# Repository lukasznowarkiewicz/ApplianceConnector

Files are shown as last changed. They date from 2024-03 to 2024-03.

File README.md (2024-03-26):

# Appliance connector

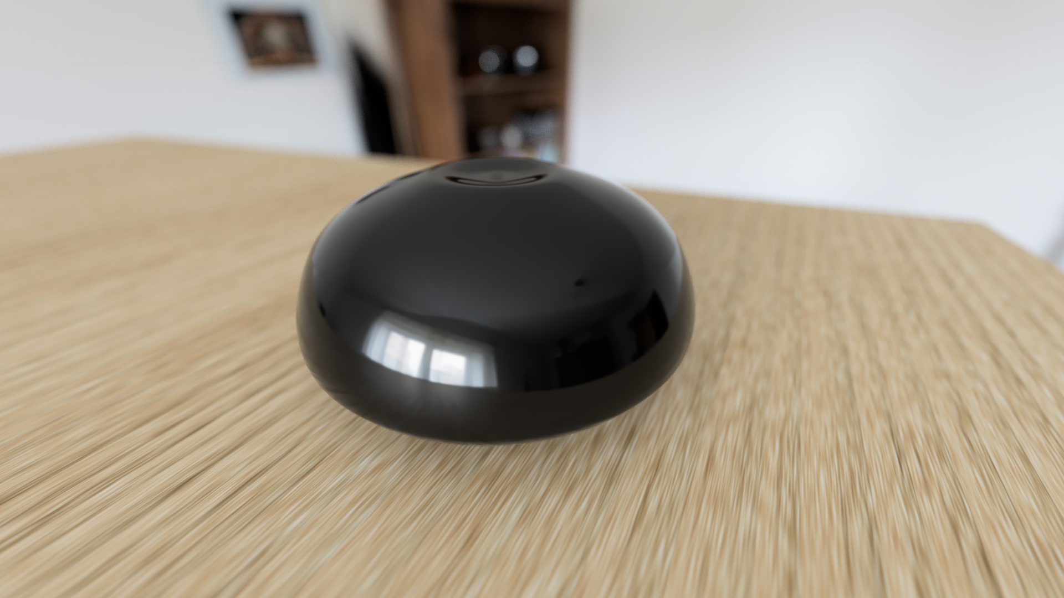
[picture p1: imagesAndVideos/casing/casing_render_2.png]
Applicance connector render


## Initial idea - visible gap on the market

The history behing this device came from my experience - I used to install smart home systems and saw some market gap in integrating smart home devices which oryginally was not intended to be "smart". I have in mind devices controlled over infrared, like air condationers, TVs, home theaters, audio systems, satellite and cable boxes, projectors, controlled over serial port (RS-232), like projectors, some audio entertainment systems, video conferencing systems, surveillance camera systems, etc., finishing on most simple, controlled with dry contact, like garage and gate openers, access control systems or blinds and curtains systesm, to just name a few. Backbone of most smart home systems in the end, almost always is TCP/IP network. Proabably the most universal method between both vendor locked and open smart home systems is communication via REST API. This device main prupose was to cover this gap, allow integration of all listed devices in thoughtfully manner. 

## Similar devices

Back in 2019, when we were working on this device, already some alternatives existed. There were deivces, which adresses only part of the problem. To list a few:

### Global Cache iTach

- **Pros**: Supports various connection options, compact, compatible with many systems.
- **Cons**: Setup complexity, may not suit simple needs, separate devices for RS232 and IR, high price

### BroadLink RM Pro+

- **Pros**: Affordable, supports IR and RF 433MHz, works with major voice assistants.
- **Cons**: RF control issues reported, app usability, lack of REST API.

### Remotec AC Master ZXT-600

- **Pros**: Specialized for AC control, supports major brands, energy-efficient.
- **Cons**: Limited to AC, setup complexity with certain hubs, lack of REST API.

### Blastbot IR Blaster

- **Pros**: Smartphone and voice control, supports schedules.
- **Cons**: Cloud dependency, IR only, lack of REST API.

### Remotec ZXT-310US

- **Pros**: Z-Wave to IR for AV devices, supports learning IR codes.
- **Cons**: Focus on AV, manual configuration for uncommon devices, lack of REST API.

### Hank IR Transceiver

- **Pros**: Z-Wave Plus, IR learning, compact.
- **Cons**: AV control focus, setup technicality, lack of REST API.

### Xiaomi Universal IR Remote Controller

- **Pros**: Very affordable, wide device support, integrates with Mi Home.
- **Cons**: Wi-Fi dependency, app/setup challenges for non-Chinese speakers, lack of REST API.

### Logitech Harmony

- **Pros**: Broad device compatibility, advanced automation, supports multiple connection types.
- **Cons**: Higher cost, discontinued models may affect support, lack of REST API.

## First prototype

First prototype was rough. Designed in `Autodesk Eagle` (shortly after buying it from CadSoft). It only purpose was to get rid off breadboards, which often cause more problems than circuit itself. This devkit was an extension to `Lolin32 Lite` prototyping board. This board I would call as "it ain't much, but it honest work" and most important allowed us quick start working on the software.

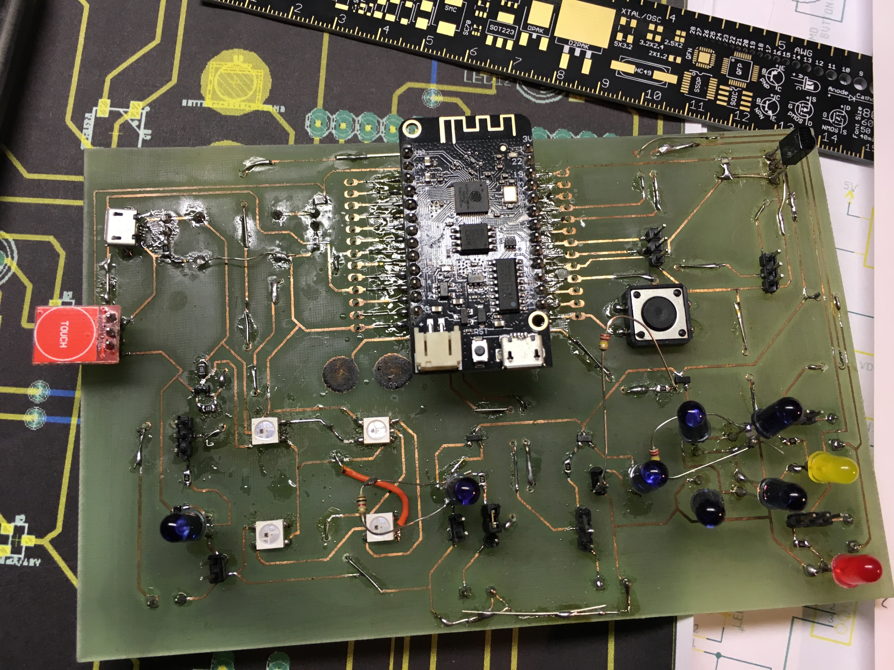
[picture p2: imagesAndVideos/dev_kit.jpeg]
DevKit photo


It has necessary components for testing initially agreed functionalities:
- IR leds for controlling devices
- IR receiver `PNA460XM`
- two experimental touch buttons (ESP32 has itself option for capacitive buttons support, but in the end we were unable to figure out how to make it work)
- connector for `TTTP223` based touch button module
- `WS2812B` Leds for showing status of the device
  
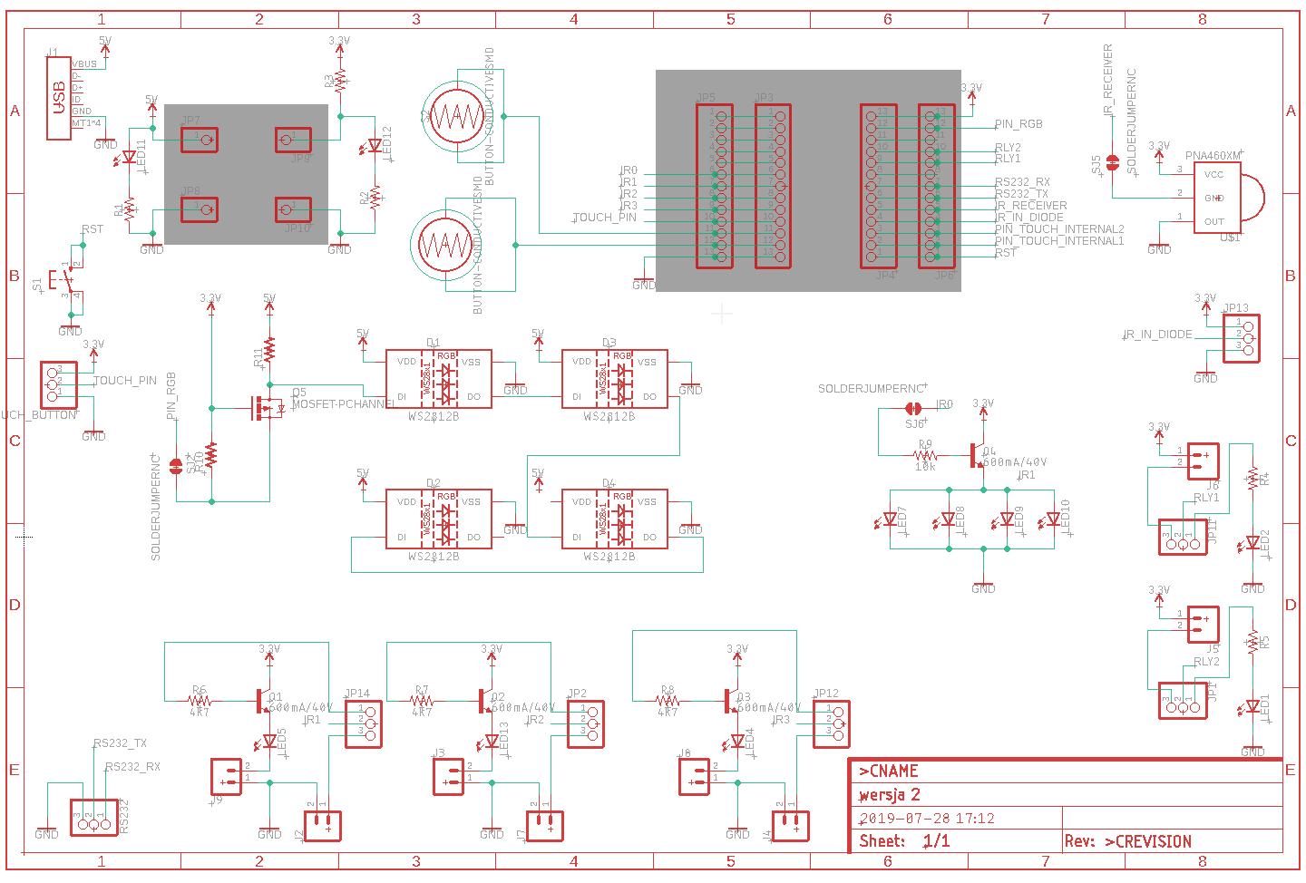
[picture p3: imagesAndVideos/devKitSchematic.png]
DevKit schematic


## Functional requirements and UI design

At this point we more or less know how device should function, which features implement. Form of the device was not clear yet, but anyway it didn't stop us from working on software. Basic user interface was designed in `Affinity Designer`. Simple mockup of the software, not functional, but give us good base for creating user interface in web technologies.

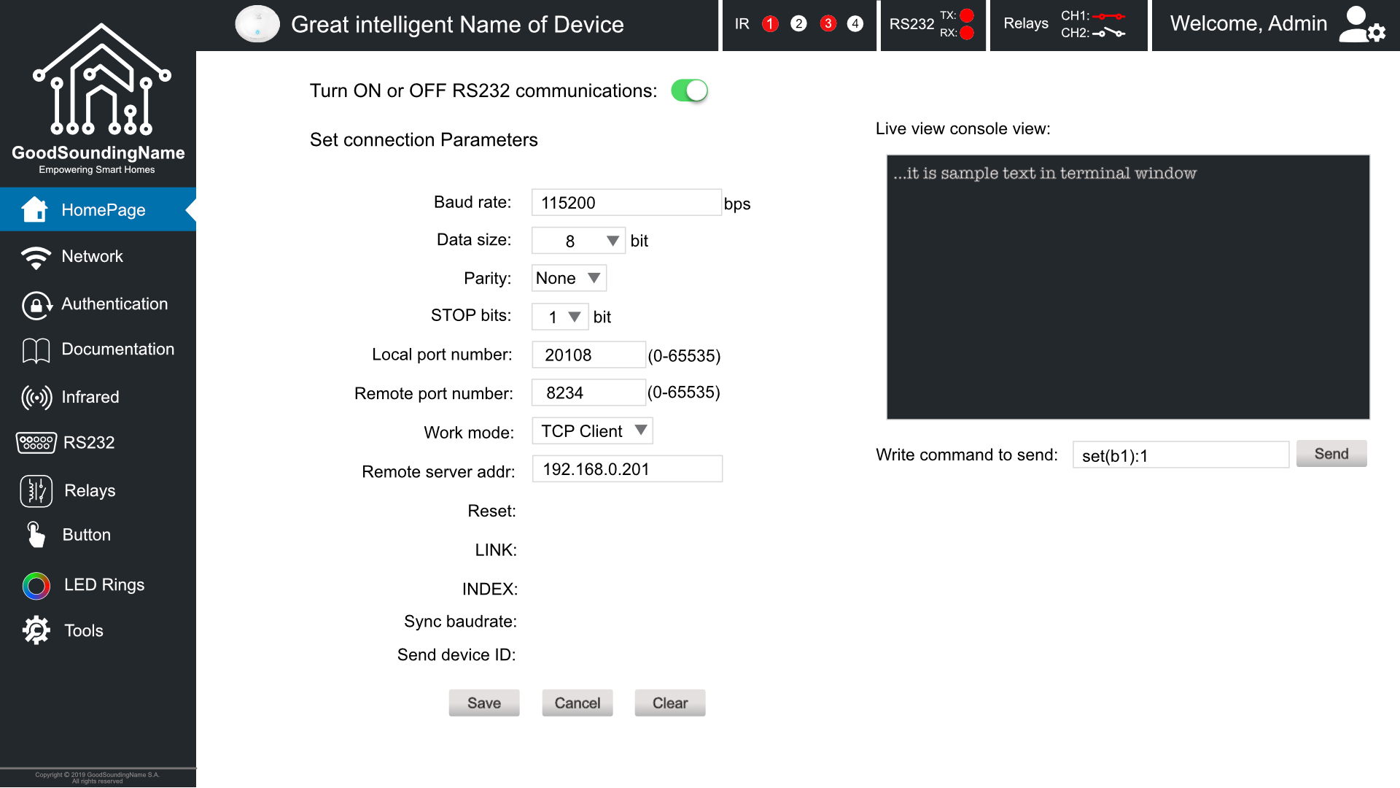
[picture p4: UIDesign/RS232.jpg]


## Software Development

The web server runs directly on the ESP32, necessitating that the webpage be as simple and lightweight as possible. With only 4MB of storage available, every kilobyte counted. Most images used were .svg, and wherever feasible, they were generated using CSS to save space.

The ESP32 operates on `ESP-IDF FreeRTOS`. Developing such an advanced application in plain C—especially incorporating functions like Wi-Fi connection, filesystem management, and web server functionalities—would significantly increase the app's complexity.

### Frontend

Given the storage limitations, the frontend was designed to be straightforward and lightweight. This is why we opted not to use any frameworks for creating the GUI. It was crafted using simple HTML, with CSS for styling and JavaScript for websockets to minimize overhead and ensure efficiency.

https://github.com/lukasznowarkiewicz/ApplianceConnector/assets/82212257/3271daf3-c359-4126-b65f-c0a6bbfbe71e

### Backend

The backend of this application on the ESP32, utilizing ESP-IDF FreeRTOS, comprises various components, each managed by specific files:

- **Webserver**: `webserver.c` and `webserver.h` handle HTTP requests, serving the GUI files and processing API calls from the frontend. `webserver_types.h` likely defines the structures and enums used by the webserver.

- **Wi-Fi Connection**: `netConf.c` and `netConf.h` are responsible for configuring the Wi-Fi connection, handling tasks such as connecting to the Wi-Fi network and managing network settings.

- **Infrared Control**:
  - Sending IR commands: `irsend.c` and `irsend.h` manage the sending of IR commands to devices.
  - Receiving IR commands: `irrecv.c` and `irrecv.h` handle the reception of IR signals from remote controls.

- **UART Communication**: `tcpserial.c` and `tcpserial.h` handle of UART communication.

- **LED Control**: `led.c` and `led.h` are used for controlling LED indicators on the ESP32, such as showing the status of the device or Wi-Fi connection.

- **Relay Control**: `relay.c` and `relay.h` manage the activation and deactivation of relays for controlling dry contacts.

- **Button Input**: `button.c` and `button.h` handle input from physical buttons on the ESP32 device, allowing for user interaction without the web interface.

### Testing infrared

Testing receiving commands from IR:

https://github.com/lukasznowarkiewicz/ApplianceConnector/assets/82212257/00d33be0-9f63-4c23-b90f-50ff3d0fc727

Testing sending commands over IR:

https://github.com/lukasznowarkiewicz/ApplianceConnector/assets/82212257/5f554944-b339-42f7-858e-584611f51841

Saving received commands to text file (as a config):

https://github.com/lukasznowarkiewicz/ApplianceConnector/assets/82212257/204f5668-1959-4dcd-b433-fa26de5b123a

### Testing UART

https://github.com/lukasznowarkiewicz/ApplianceConnector/assets/82212257/dbb3c007-76f6-457e-a3c8-33a27682dad4

### Testing relays

https://github.com/lukasznowarkiewicz/ApplianceConnector/assets/82212257/7d674879-574c-41a6-804a-36f65532bcf2

## Enclosure

After we made first functioning prorotype - it was time to pack this device into sleek housing. Many ideas was both designed and 3d printed. 

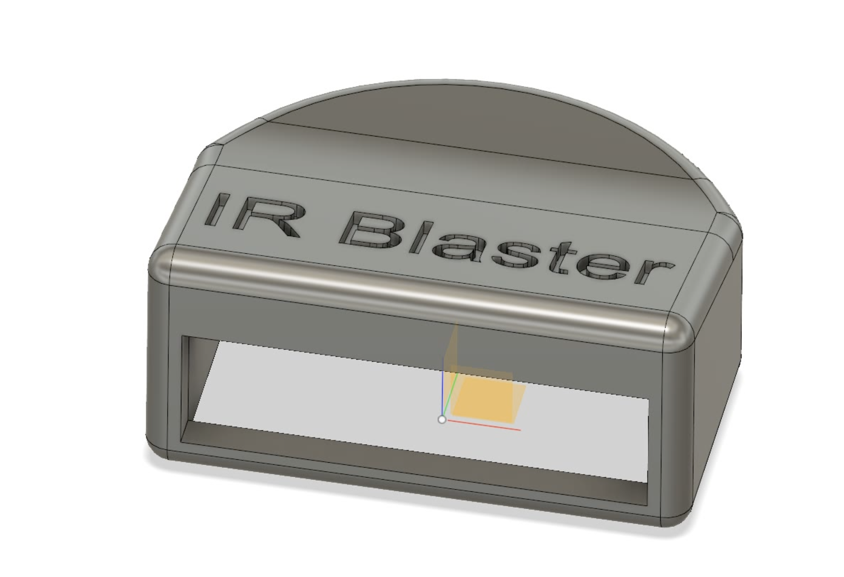
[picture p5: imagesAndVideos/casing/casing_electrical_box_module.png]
Applicance connector casing brainstorming 1


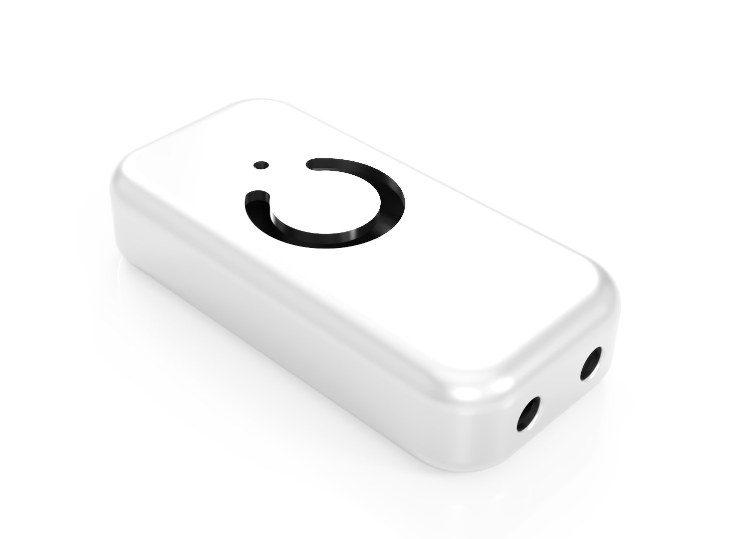
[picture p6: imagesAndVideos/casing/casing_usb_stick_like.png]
Applicance connector casing brainstorming 2


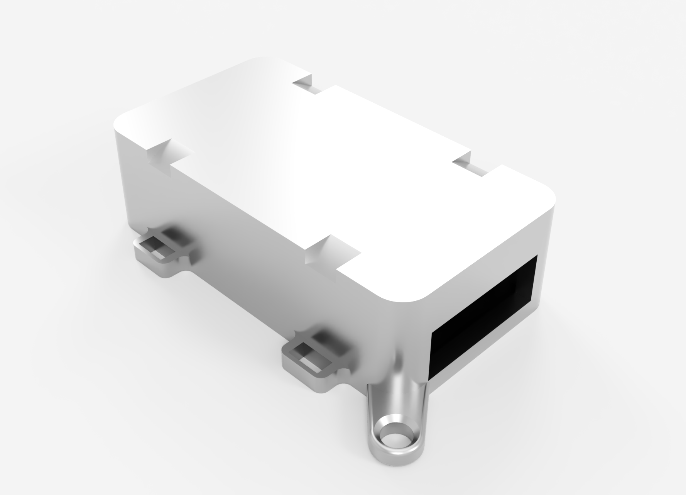
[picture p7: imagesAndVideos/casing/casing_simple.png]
Applicance connector casing brainstorming 3


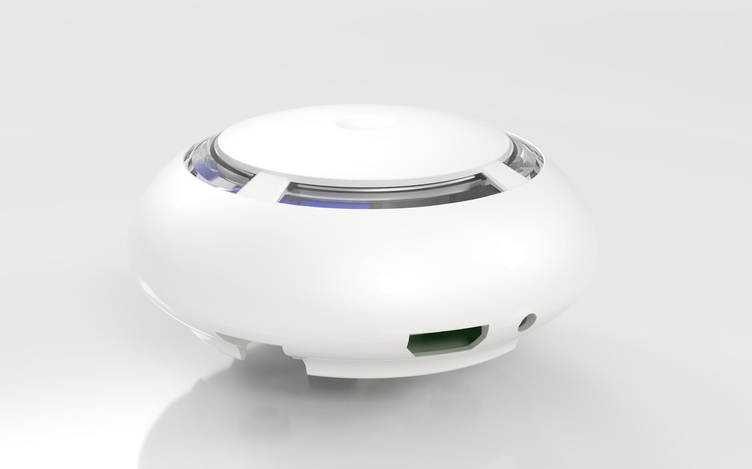
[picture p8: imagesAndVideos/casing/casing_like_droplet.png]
Applicance connector casing brainstorming 4


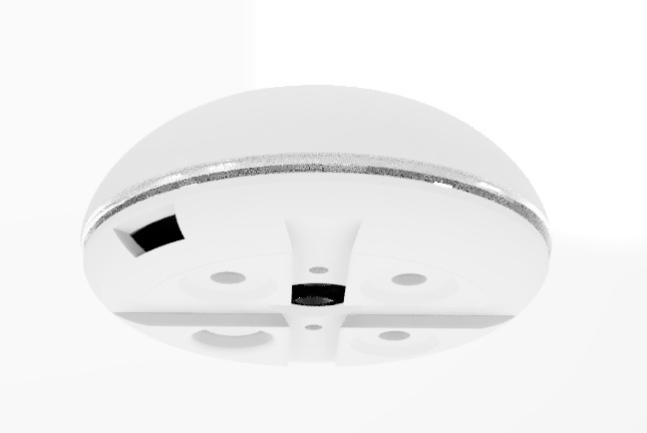
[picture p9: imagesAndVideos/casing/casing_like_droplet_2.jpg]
Applicance connector casing brainstorming 4


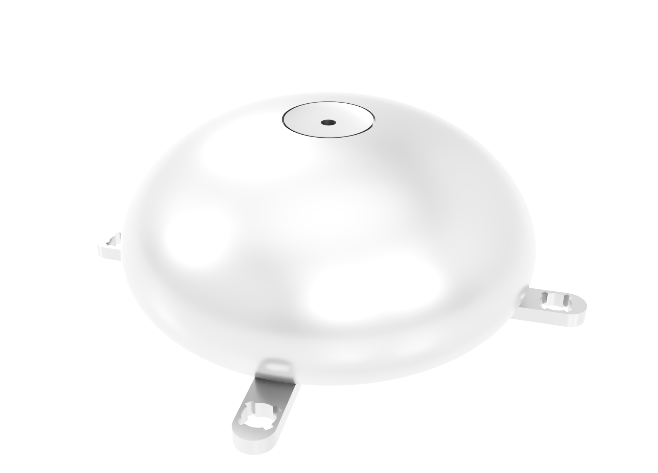
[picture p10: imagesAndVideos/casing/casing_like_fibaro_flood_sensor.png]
Applicance connector casing brainstorming 5


Casing was designed in Fusion360:
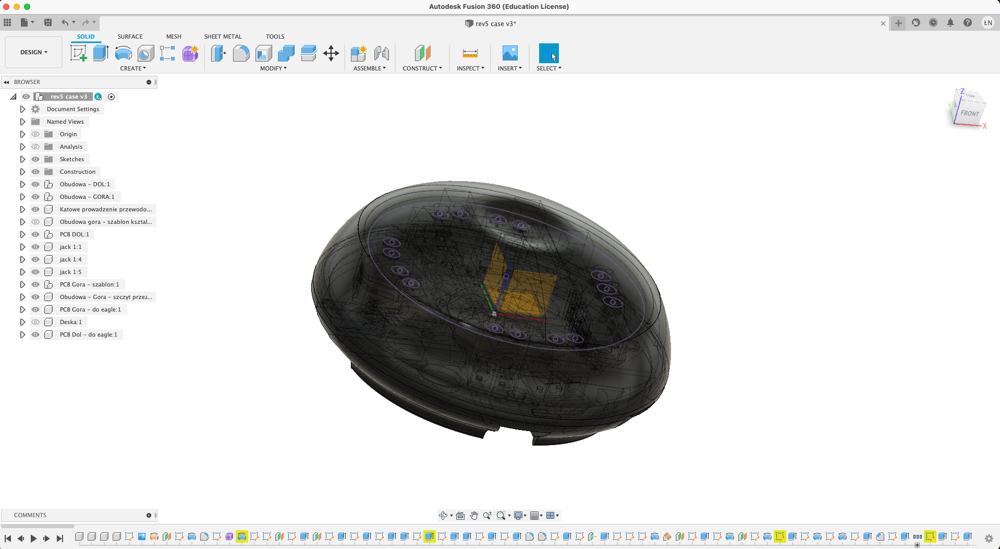
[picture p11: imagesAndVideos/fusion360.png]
Fusion 360


REV 5 is the last casing we stick to and designed custom board for it. It has touch button on the top, translucent casing allowing both IR and visible light from RGB LEDs to go through, place at the bottom for slide-in mounting brackets (allowing for mounting it on the ceiling, to ziptie to something, etc.)

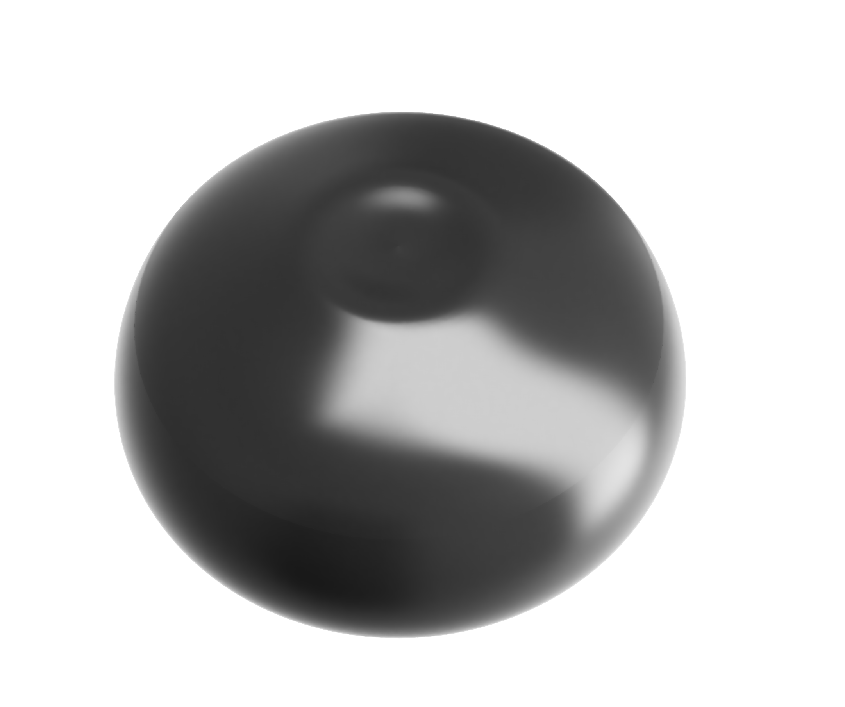
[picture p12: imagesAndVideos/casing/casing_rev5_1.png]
Applicance connector casing rev 5


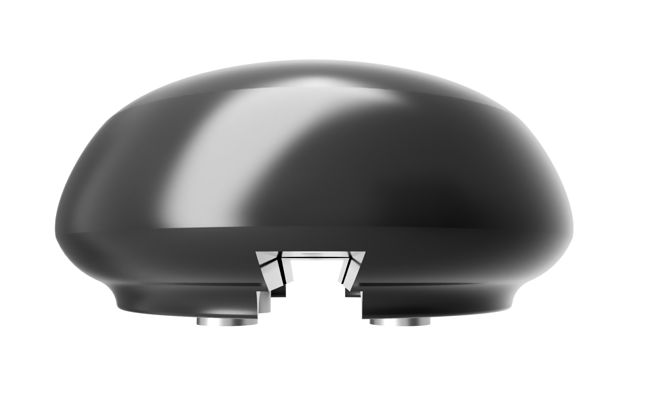
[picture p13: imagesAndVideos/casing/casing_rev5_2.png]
Applicance connector casing rev 5


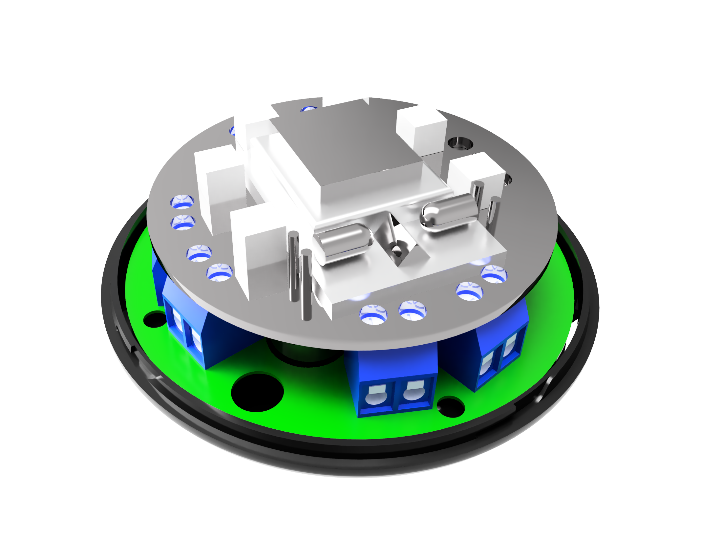
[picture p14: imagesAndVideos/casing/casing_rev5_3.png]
Applicance connector casing rev 5


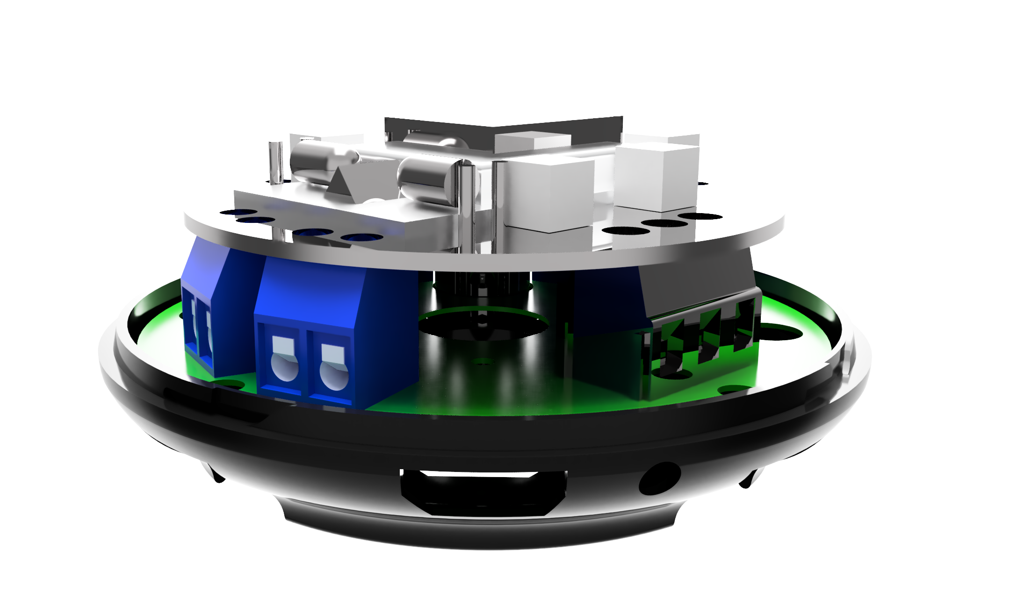
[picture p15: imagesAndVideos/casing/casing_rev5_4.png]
Applicance connector casing rev 5


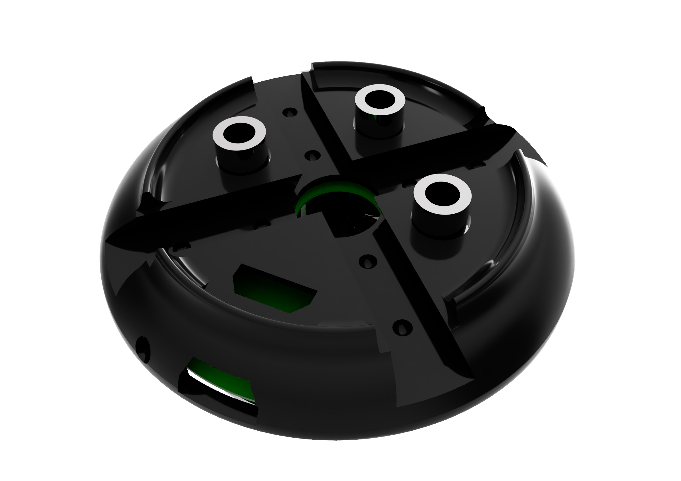
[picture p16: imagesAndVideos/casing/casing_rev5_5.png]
Applicance connector casing rev 5


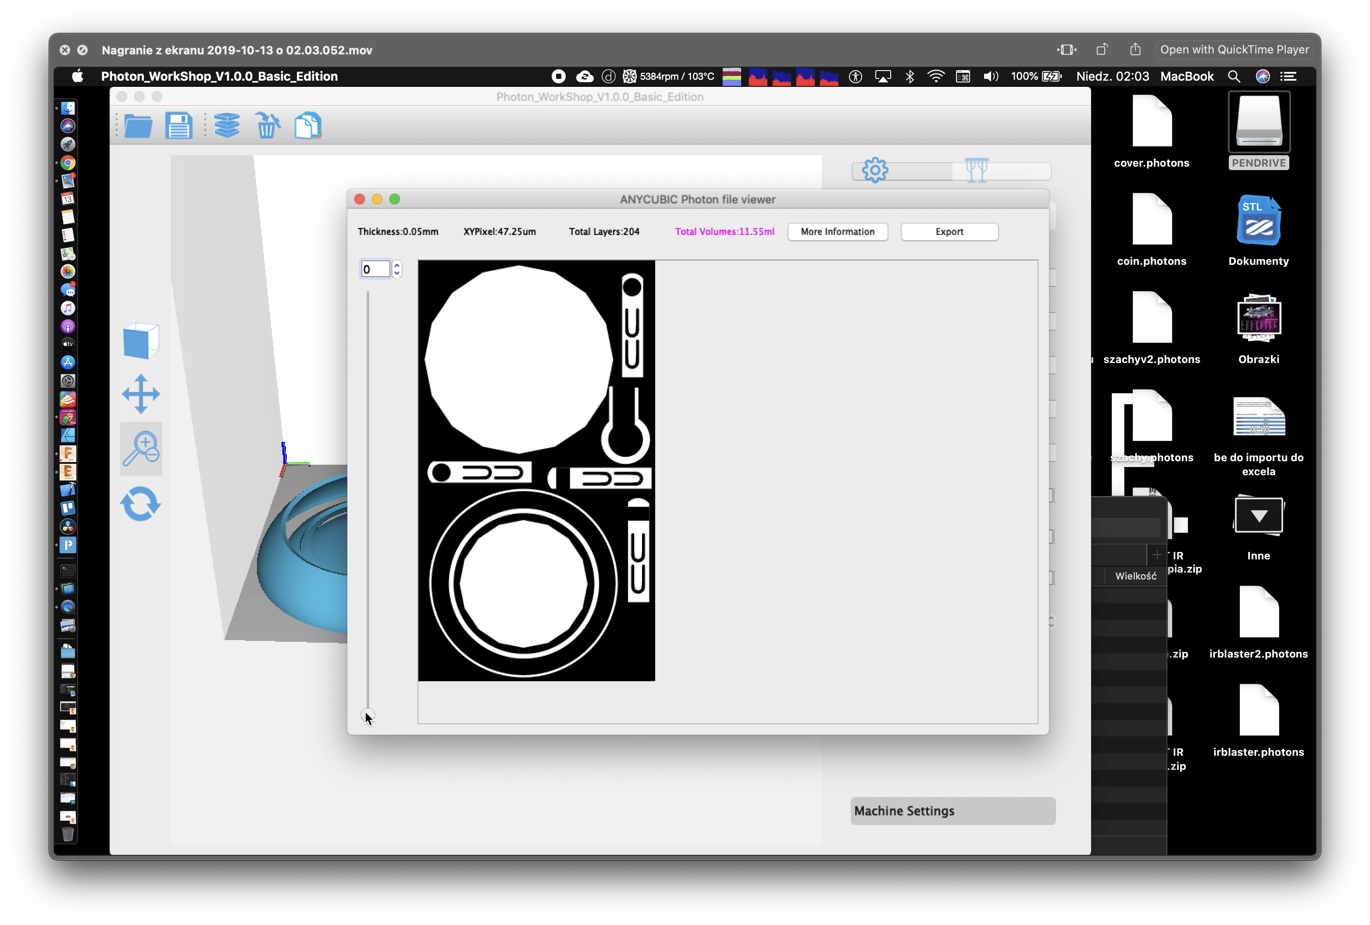
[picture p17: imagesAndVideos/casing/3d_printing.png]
3D printing case1


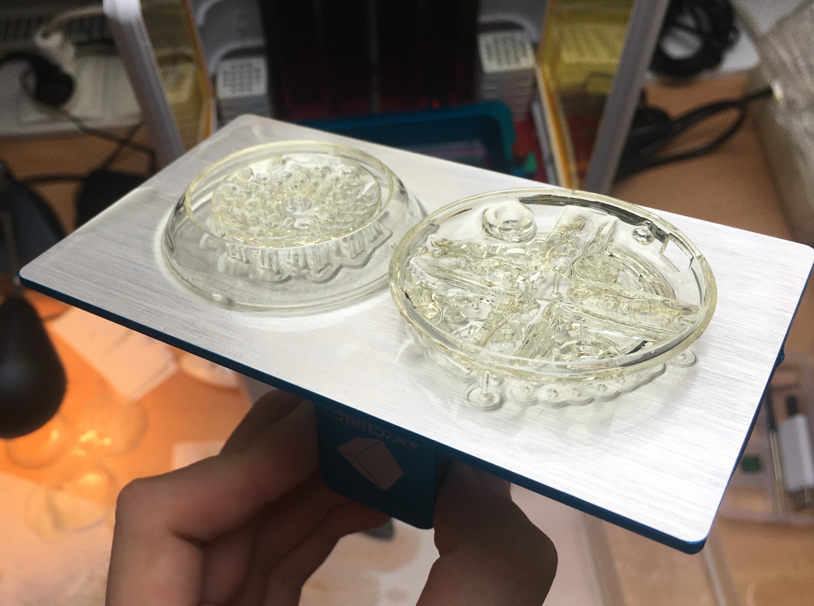
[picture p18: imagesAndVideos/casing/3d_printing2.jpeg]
3D printing case2


## Hardware

Electronic part of the design consists mainly on two boards:
- upper one with ESP32 module, IR LEDs and IR receiver
- lower one with terminal blocks for screwing wires of the RS232 device, dry contact controlled deivces, supply power via terminal block, side or bottom micro-USB cable and headphone jacks for connecting remote IR transmitters. Hole in the middle allow guiding wires through and then wrap them around the deivce.

In the folder `hardwareElectronics` `Eagle` project can be found. Unfortunately the most recent version has been lost and I've simply attached the last backup I could find.

## Project abandon

Due to start of the studies and lack of free time, this project died spontaneously. Now when I'm pushing those assets and writing this readme (about the time of finishing my masters degree) I look at it with a wink. Today with ease I've found a few of the market devices doing exactly that. Even cool project ESPHome does exactly that. But overall at the time it was great experiece.

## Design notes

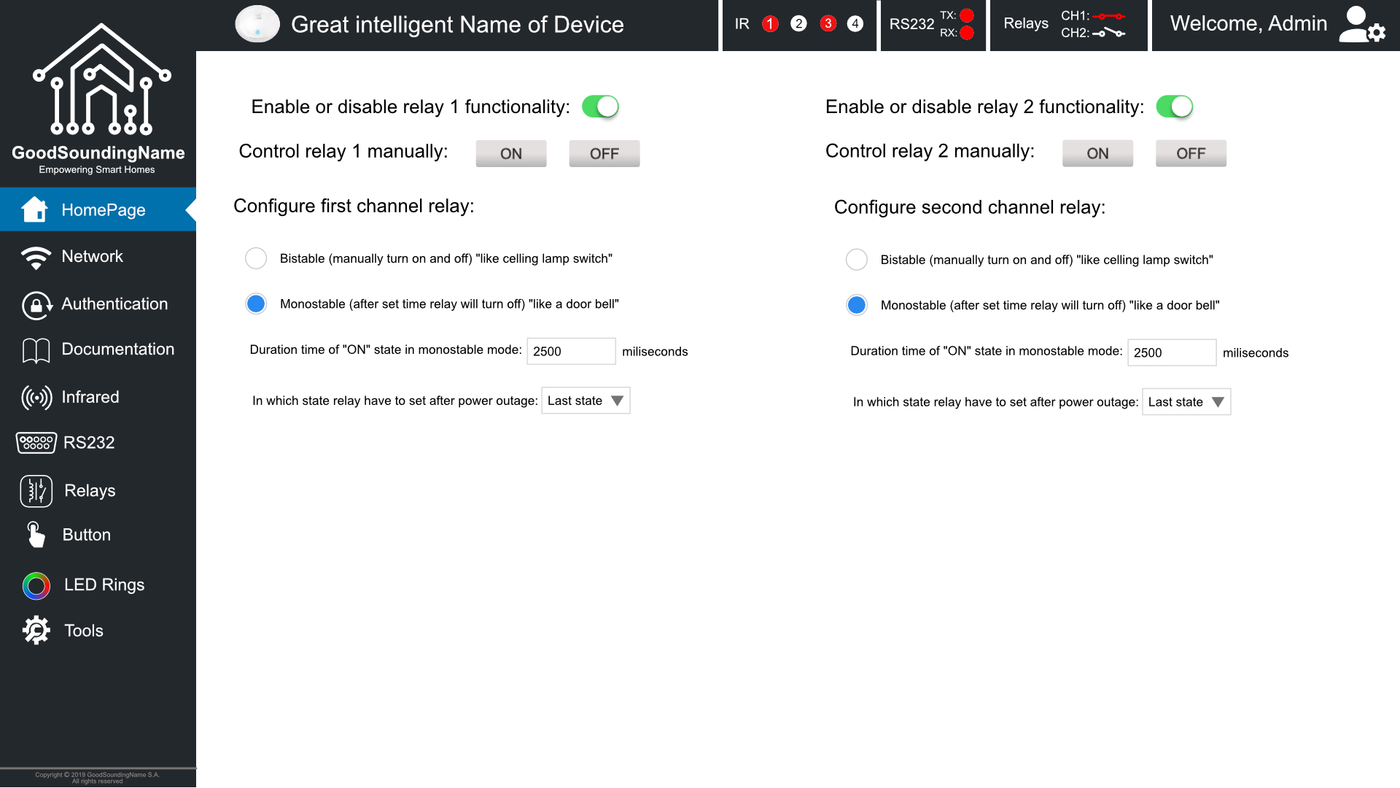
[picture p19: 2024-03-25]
UIDesign/Relays.jpg

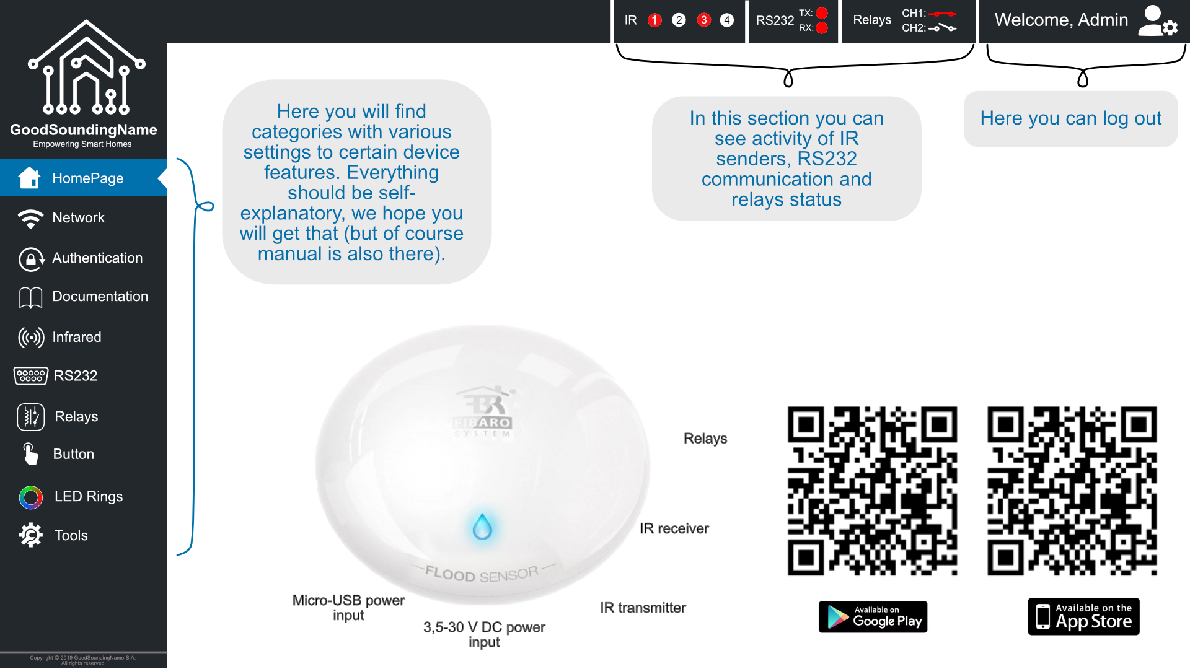
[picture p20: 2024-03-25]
UIDesign/MainPage.jpg

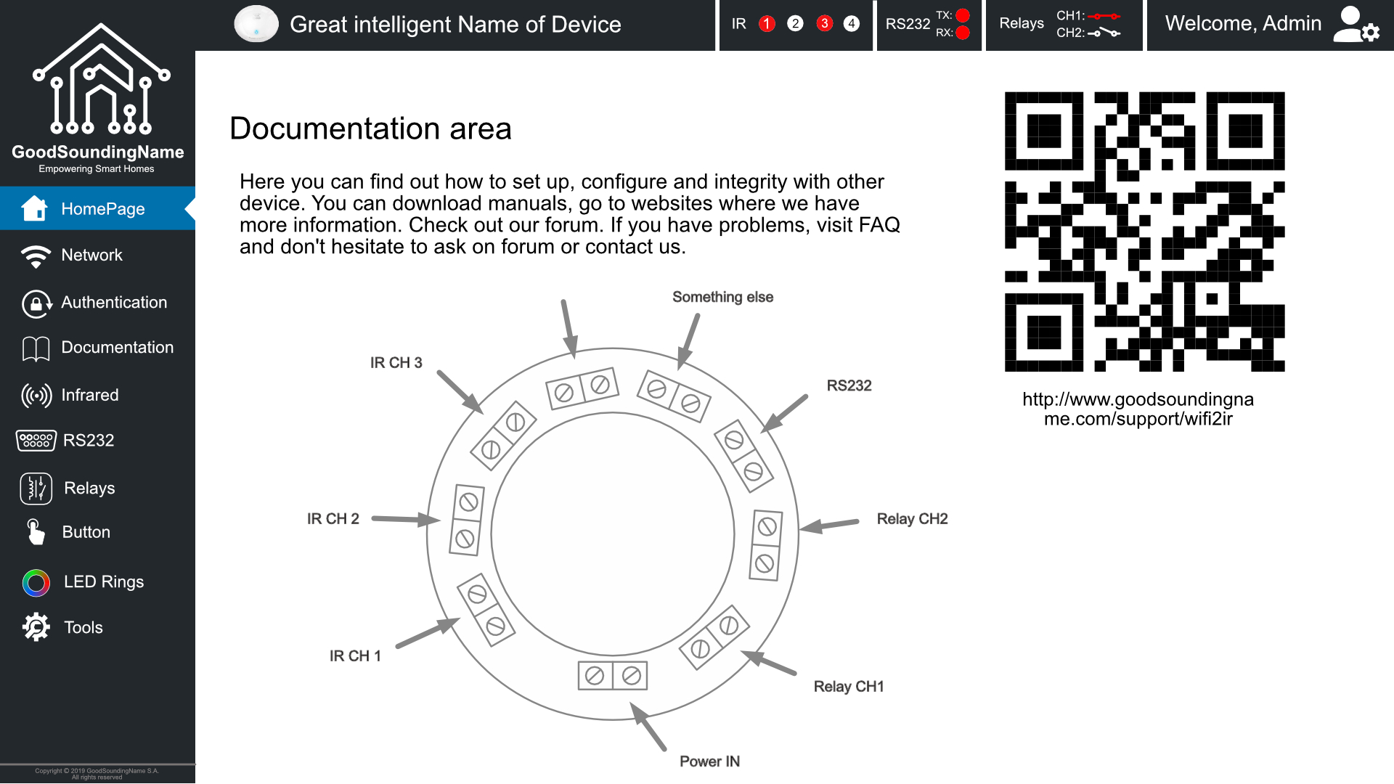
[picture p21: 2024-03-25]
UIDesign/Documentation.jpg

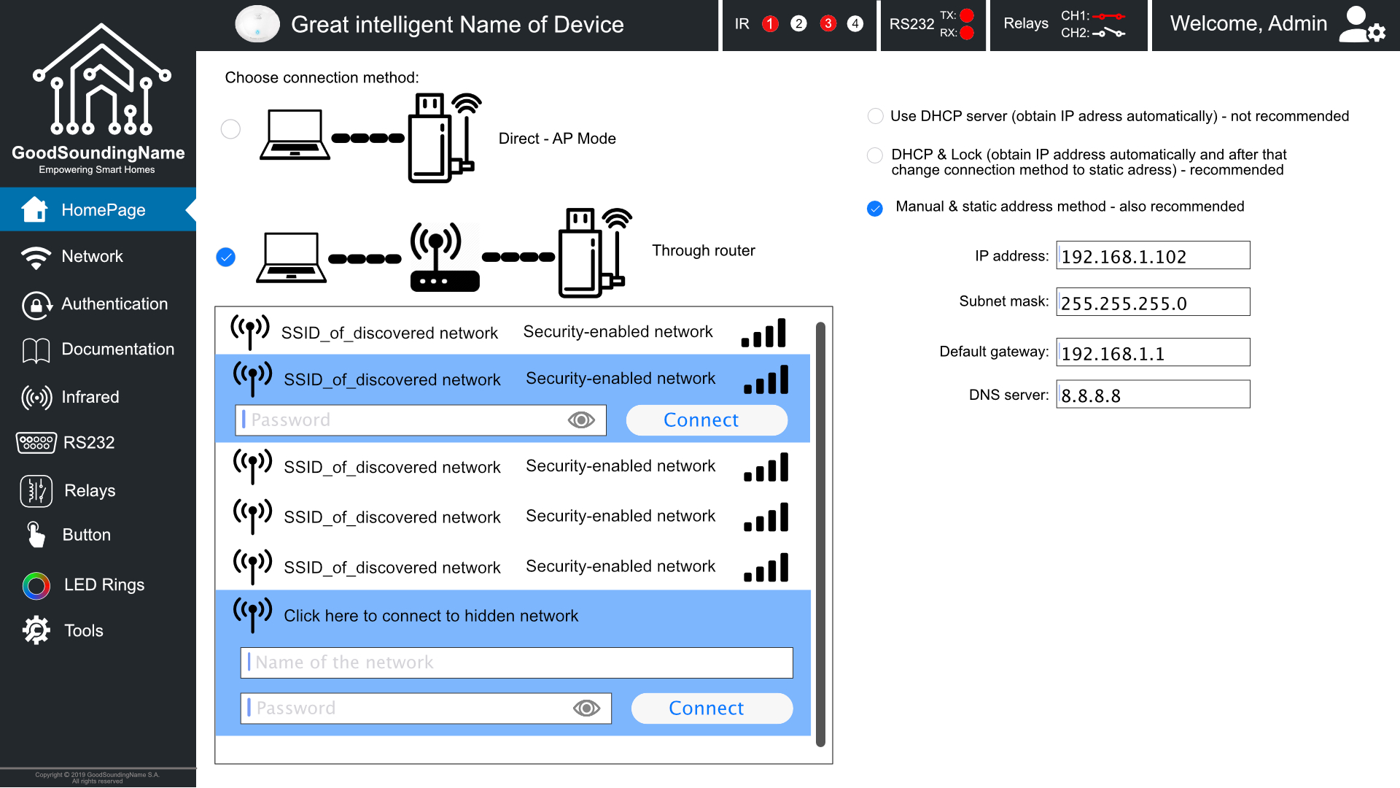
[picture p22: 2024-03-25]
UIDesign/Network.jpg

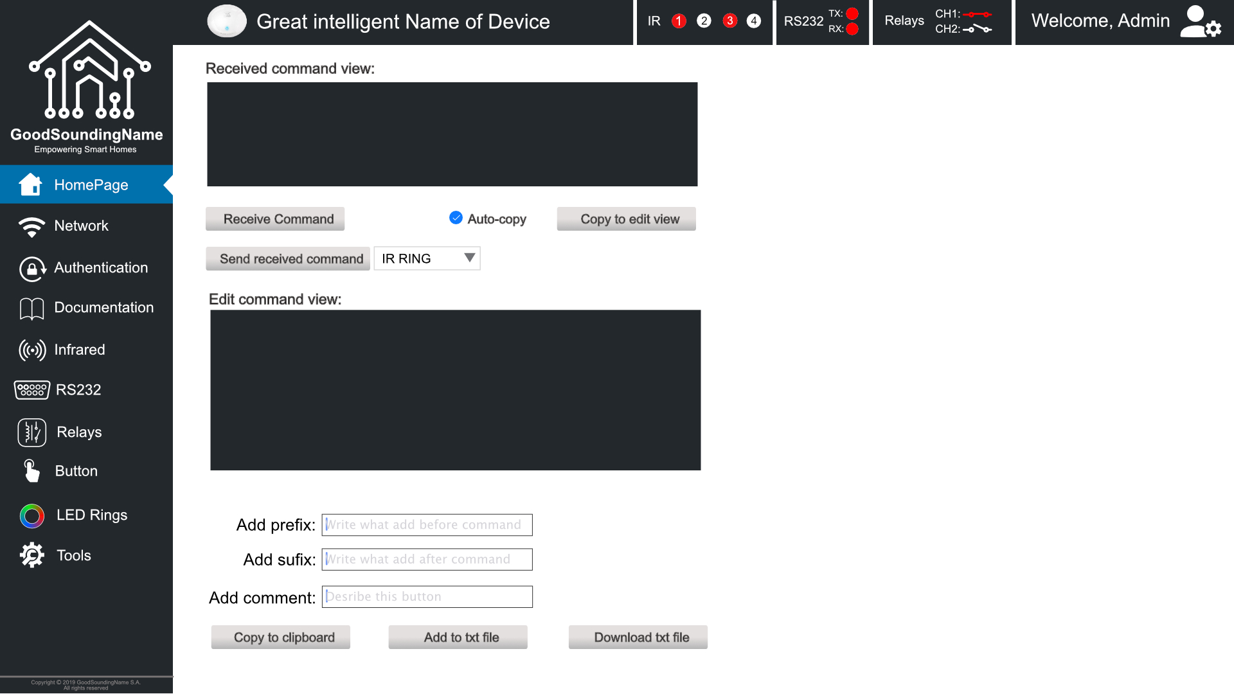
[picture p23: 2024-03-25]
UIDesign/infrared.jpg

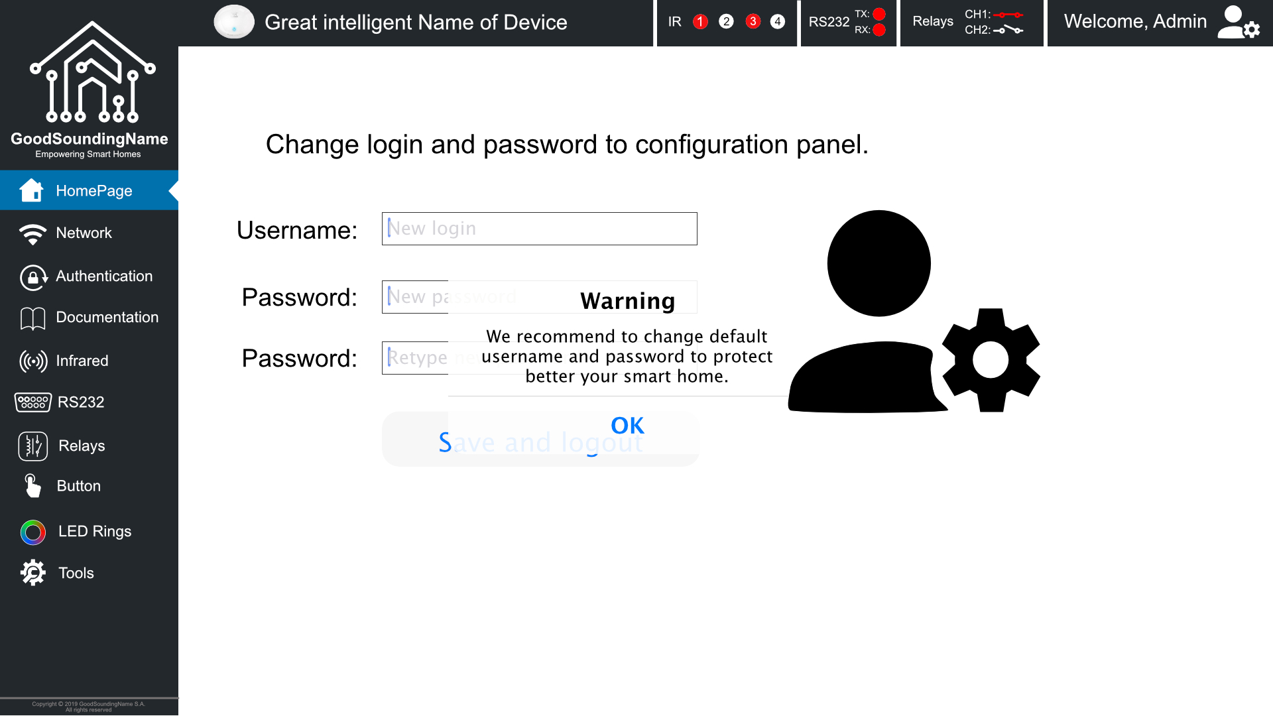
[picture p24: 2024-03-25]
UIDesign/authentication.jpg

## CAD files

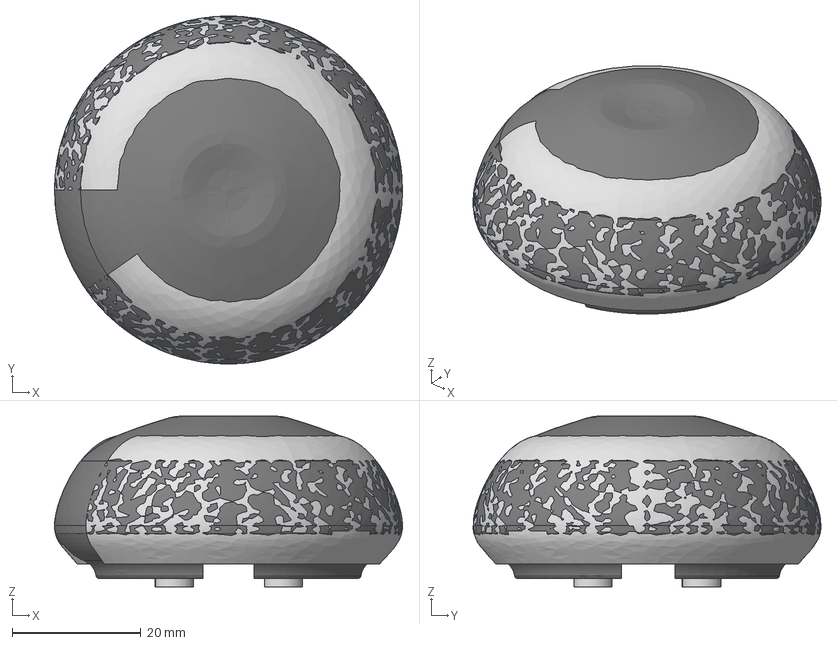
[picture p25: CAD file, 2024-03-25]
hardwareMechanical/rev5 case v2.step
54.1 x 54.1 x 26.6 mm
Obudowa - DOL
wypust do blokowania x 3
Katowe prowadzenie przewodow
Obudowa gora - szablon ksztaltu
Board
SCREWTERMINAL-3_5MM-2 x 6
jack 1 x 3
ESP32
LED IR SMD x 6
Guzik dotykowy
Led IR 5mm x 2
odblysnik IR
Obudowa - Gora - szczyt przezroczysty
PCB Gora - do eagle
PCB Dol - do eagle

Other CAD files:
hardwareElectronics/EAGLE/projects/IR BLASTER/PCB V4/ark 3 pin 3D.f3d
hardwareElectronics/EAGLE/projects/IR BLASTER/PCB V4/terminal 2 pin.f3d

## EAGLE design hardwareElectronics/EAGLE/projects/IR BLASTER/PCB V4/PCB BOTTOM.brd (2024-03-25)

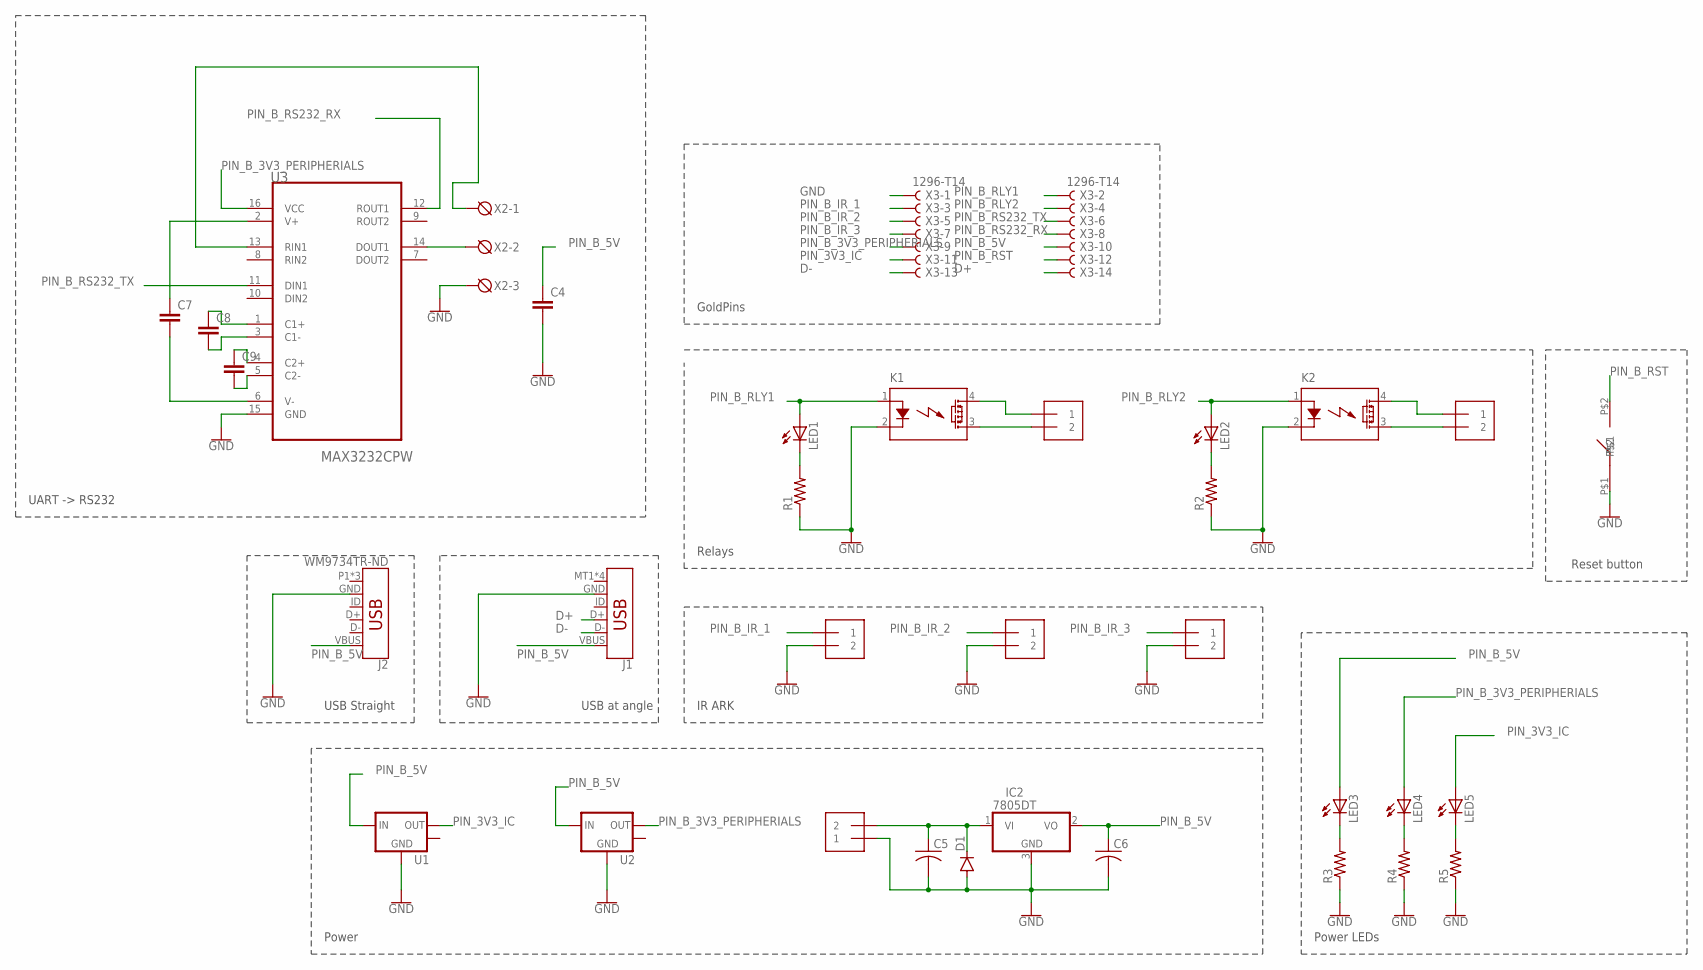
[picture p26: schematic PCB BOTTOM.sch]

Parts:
C4, C7, C8, C9: C-EUC0805K; C0805K
C5, C6: C-USC1206K; C1206K
D1: DIODE-SOD80C; SOD80C
IC2: 7805DT; TO252
IR1, IR2, IR3: 1X2-3.5MM
J1: USB_MICRO-B_SMT; USB-MICROB
J2: WM9734TR-ND; USB-B-MICRO-SMD_VERT
K1, K2: CPC1008N; SOIC-4-2.54
LED1, LED2, LED3, LED4, LED5: LEDCHIP-LED0805; CHIP-LED0805
PWR: 1X2-3.5MM
R1, R2, R3, R4, R5: R-US_M0805; M0805
RLY1, RLY2: 1X2-3.5MM
U1, U2: LM1117-1.8; SOT223
U3: MAX3232CPW; SOP65P640X120-16N
U$1: MICRO_SWITCH_AT_ANGLE
X2: DG3XX-03-3.5; DG350-3.5-03P
X3: 1296-T14; 1296-14

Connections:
D+: J1.D+, X3.14
D-: J1.D-, X3.13
GND: C4.2, C5.2, C6.2, D1.A, IC2.3 (GND), IR1.2, IR2.2, IR3.2, J1.GND, J2.GND, K1.2 (K), K2.2 (K), PWR.1, R1.1, R2.1, R3.1, R4.1, R5.1, U1.1 (GND), U2.1 (GND), U3.15 (GND), U$1.P$1, X2.3, X3.1
unnamed: K1.3 (D2), RLY1.2
unnamed: K1.4 (D1), RLY1.1
unnamed: LED1.C, R1.2
unnamed: K2.3 (D2), RLY2.2
unnamed: K2.4 (D1), RLY2.1
unnamed: LED2.C, R2.2
unnamed: U3.14 (DOUT1), X2.2
unnamed: U3.13 (RIN1), X2.1
unnamed: LED3.C, R3.2
unnamed: LED4.C, R4.2
unnamed: LED5.C, R5.2
unnamed: C7.1, U3.2 (V+)
unnamed: C7.2, U3.6 (V-)
unnamed: C9.1, U3.4 (C2+)
unnamed: C9.2, U3.5 (C2-)
unnamed: C8.2, U3.3 (C1-)
unnamed: C5.1, D1.C, IC2.1 (VI), PWR.2
unnamed: C8.1, U3.1 (C1+)
PIN_3V3_IC: LED5.A, U1.2 (OUT), X3.11
PIN_B_3V3_PERIPHERIALS: LED4.A, U2.2 (OUT), U3.16 (VCC), X3.9
PIN_B_5V: C4.1, C6.1, IC2.2 (VO), J1.VBUS, J2.VBUS, LED3.A, U1.3 (IN), U2.3 (IN), X3.10
PIN_B_IR_1: IR1.1, X3.3
PIN_B_IR_2: IR2.1, X3.5
PIN_B_IR_3: IR3.1, X3.7
PIN_B_RLY1: K1.1 (A), LED1.A, X3.2
PIN_B_RLY2: K2.1 (A), LED2.A, X3.4
PIN_B_RS232_RX: U3.12 (ROUT1), X3.8
PIN_B_RS232_TX: U3.11 (DIN1), X3.6
PIN_B_RST: U$1.P$2, X3.12

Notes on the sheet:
USB Straight
USB at angle
Power
IR ARK
Power LEDs
Reset button
Relays
GoldPins
UART -> RS232

Board: 2 copper layers, 34 parts (3 on the bottom side), 32 nets, no tracks yet.

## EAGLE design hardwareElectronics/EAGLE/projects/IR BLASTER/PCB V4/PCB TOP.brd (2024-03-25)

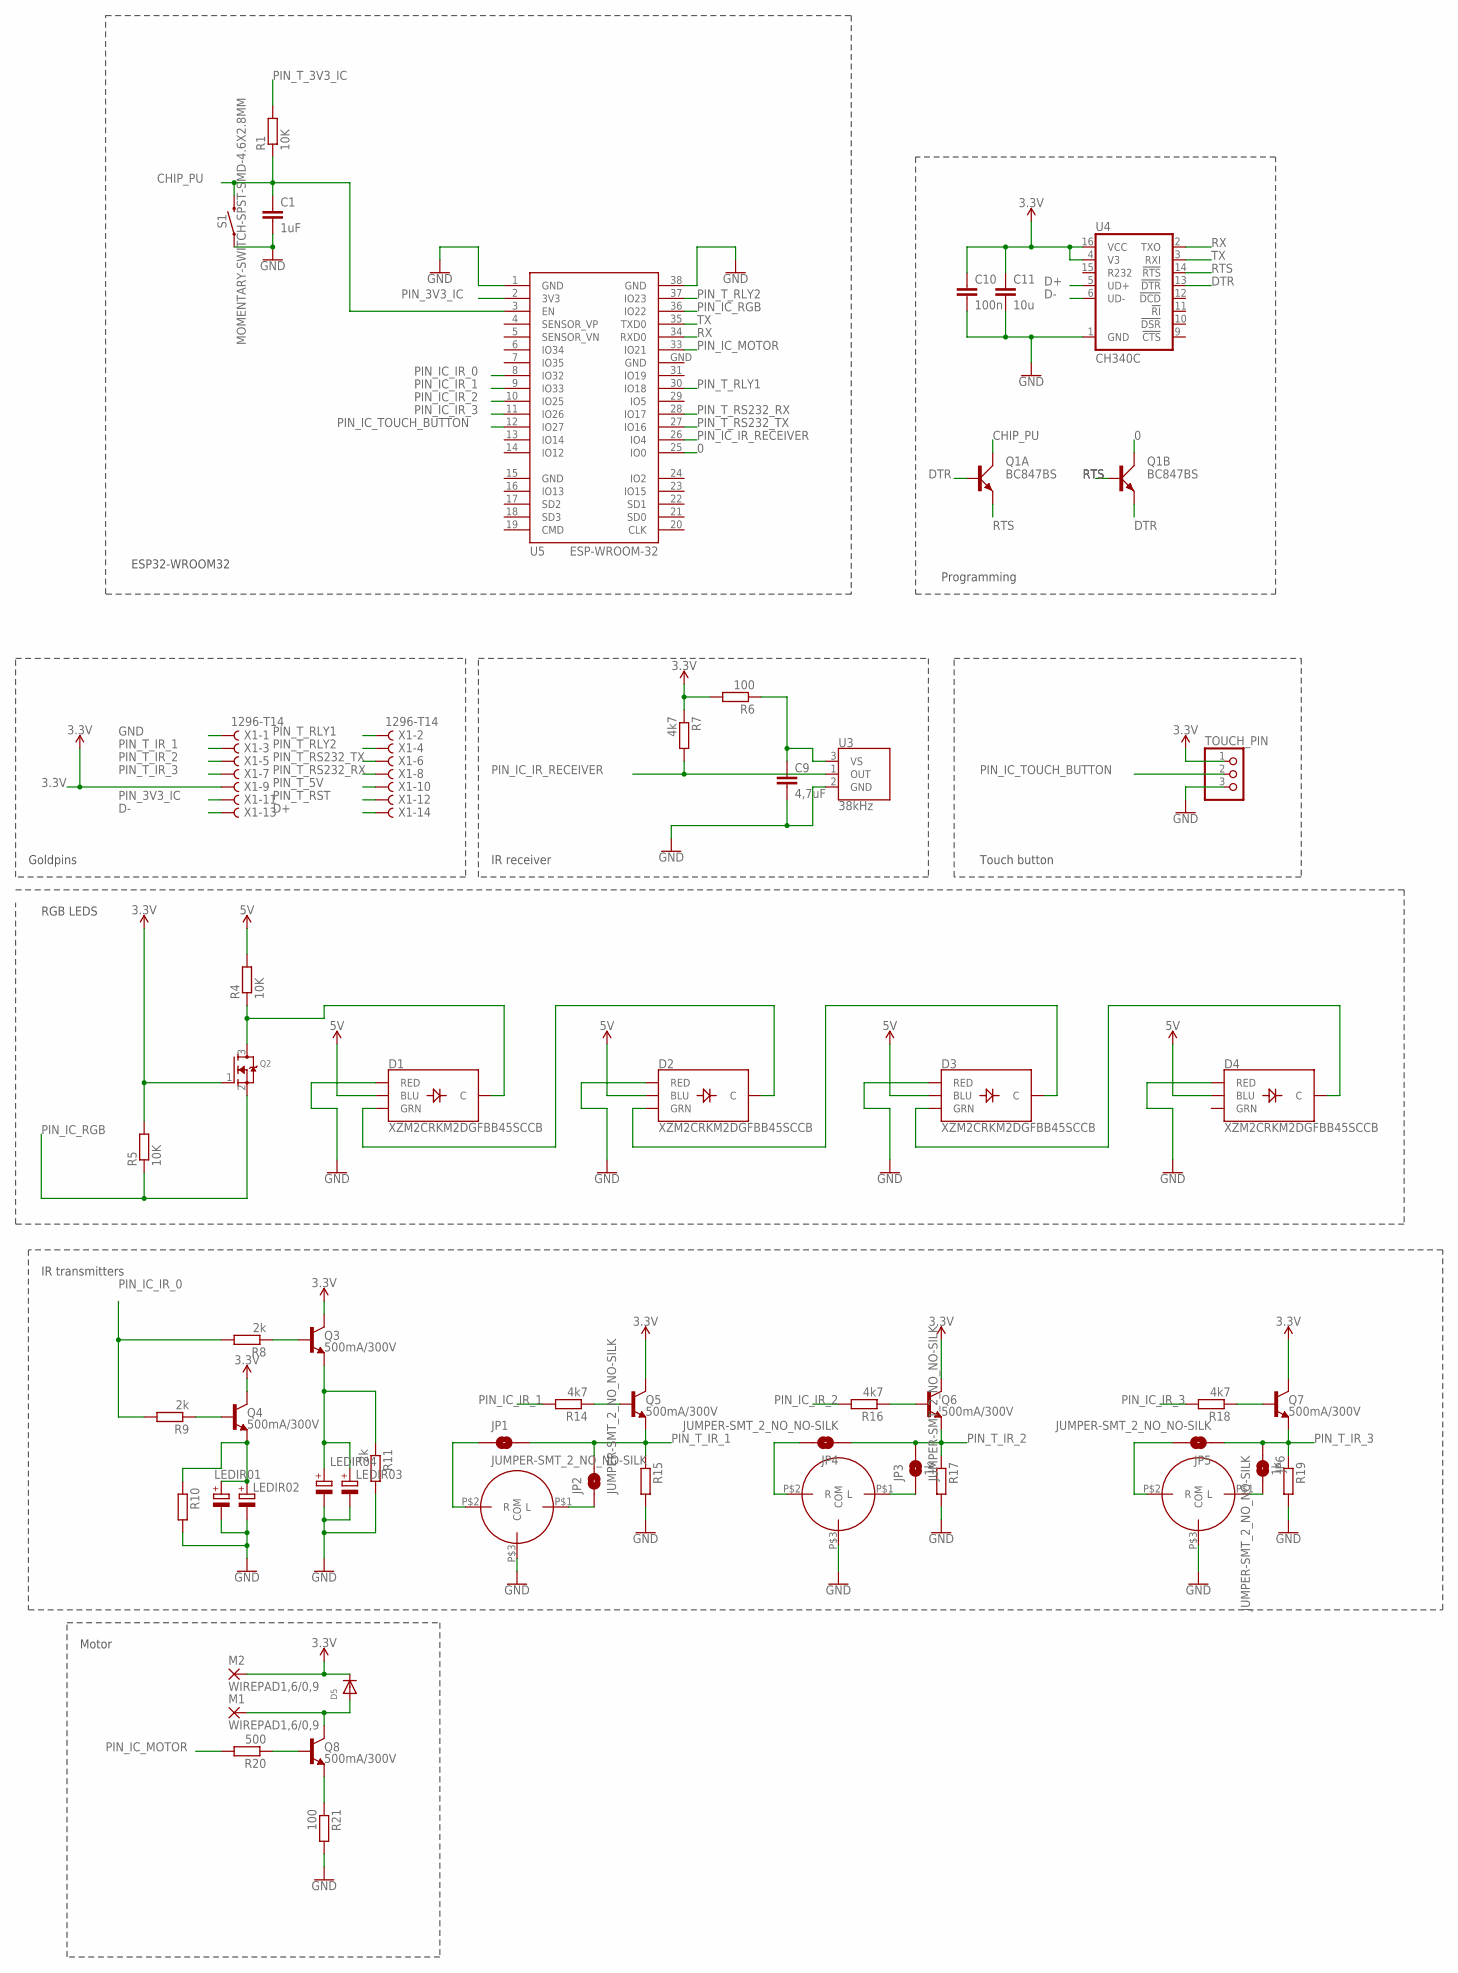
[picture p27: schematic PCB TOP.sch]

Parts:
C1: 1uF; C0603K
C9: 4,7uF; C0603K
C10: 100n; C0603K
C11: 10u; C0603K
D1, D2, D3, D4: XZM2CRKM2DGFBB45SCCB; PLCC4SMDLED
D5: DIODESOD-323F; SOD-323F
JP1, JP2, JP3, JP4, JP5, JP6: JUMPER-SMT_2_NO_NO-SILK; SMT-JUMPER_2_NO_NO-SILK
LEDIR01, LEDIR02, LEDIR03, LEDIR04: CPOL-EUB/3528-21R; B/3528-21R
M1, M2: WIREPAD1,6/0,9; 1,6/0,9
Q1: BC847BS; SOT363_PHILIPS
Q2: MOSFET-NREFLOW; SOT23
Q3, Q4, Q5, Q6, Q7, Q8: 500mA/300V; SOT23-3
R1, R4, R5: 10K; R0603
R6, R21: 100; R0603
R7, R14, R16, R18: 4k7; R0603
R8, R9, R10, R11: 2k; R0603
R15, R17, R19: 1k; R0603
R20: 500; R0603
S1: MOMENTARY-SWITCH-SPST-SMD-4.6X2.8MM; TACTILE_SWITCH_SMD_4.6X2.8MM
TOUCH_PIN: PINHD-1X3; 1X03
U3: 38kHz; TSOP382
U4: CH340C; SO016
U5: ESP-WROOM-32
U$1, U$2, U$3: JACK3.5MM
X1: 1296-T14; 1296-14

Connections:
0: Q1.3 (C), U5.25 (IO0)
3.3V: C10.1, C11.1, D5.C, M2.1, Q2.1 (G), Q3.3 (C), Q4.3 (C), Q5.3 (C), Q6.3 (C), Q7.3 (C), R5.2, R6.2, R7.1, TOUCH_PIN.1, U4.4 (V3), U4.16 (VCC), X1.9
5V: D1.3 (BLU), D2.3 (BLU), D3.3 (BLU), D4.3 (BLU), R4.2
CHIP_PU: C1.1, Q1.6 (C), R1.1, S1.3 (2), S1.4 (2), U5.3 (EN)
D+: U4.5 (UD+), X1.14
D-: U4.6 (UD-), X1.13
DTR: Q1.2 (B), Q1.4 (E), U4.13 (!DTR)
GND: C1.2, C9.2, C10.2, C11.2, D1.1 (RED), D2.1 (RED), D3.1 (RED), D4.1 (RED), LEDIR01.-, LEDIR02.-, LEDIR03.-, LEDIR04.-, R10.2, R11.2, R15.2, R17.2, R19.2, R21.2, S1.1, S1.2 (1), TOUCH_PIN.3, U3.2 (GND), U4.1 (GND), U5.1 (GND), U5.15 (GND), U5.38 (GND), U5.GND, U$1.P$3 (COM), U$2.P$3 (COM), U$3.P$3 (COM), X1.1
unnamed: JP6.2, U$3.P$1 (L)
unnamed: JP2.1, U$1.P$1 (L)
unnamed: JP1.1, U$1.P$2 (R)
unnamed: JP4.2, U$2.P$2 (R)
unnamed: JP3.1, U$2.P$1 (L)
unnamed: D1.4 (C), Q2.3 (D), R4.1
unnamed: JP5.2, U$3.P$2 (R)
unnamed: D1.2 (GRN), D2.4 (C)
unnamed: C9.1, R6.1, U3.3 (VS)
unnamed: D2.2 (GRN), D3.4 (C)
unnamed: LEDIR01.+, LEDIR02.+, Q4.2 (E), R10.1
unnamed: D3.2 (GRN), D4.4 (C)
unnamed: LEDIR03.+, LEDIR04.+, Q3.2 (E), R11.1
unnamed: Q3.1 (B), R8.1
unnamed: Q4.1 (B), R9.1
unnamed: Q5.1 (B), R14.1
unnamed: Q6.1 (B), R16.1
unnamed: Q7.1 (B), R18.1
unnamed: Q8.1 (B), R20.1
unnamed: D5.A, M1.1, Q8.3 (C)
unnamed: Q8.2 (E), R21.1
PIN_3V3_IC: U5.2 (3V3), X1.11
PIN_IC_IR_0: R8.2, R9.2, U5.8 (IO32)
PIN_IC_IR_1: R14.2, U5.9 (IO33)
PIN_IC_IR_2: R16.2, U5.10 (IO25)
PIN_IC_IR_3: R18.2, U5.11 (IO26)
PIN_IC_IR_RECEIVER: R7.2, U3.1 (OUT), U5.26 (IO4)
PIN_IC_MOTOR: R20.2, U5.33 (IO21)
PIN_IC_RGB: Q2.2 (S), R5.1, U5.36 (IO22)
PIN_IC_TOUCH_BUTTON: TOUCH_PIN.2, U5.12 (IO27)
PIN_T_3V3_IC: R1.2
PIN_T_5V: X1.10
PIN_T_IR_1: JP1.2, JP2.2, Q5.2 (E), R15.1, X1.3
PIN_T_IR_2: JP3.2, JP4.1, Q6.2 (E), R17.1, X1.5
PIN_T_IR_3: JP5.1, JP6.1, Q7.2 (E), R19.1, X1.7
PIN_T_RLY1: U5.30 (IO18), X1.2
PIN_T_RLY2: U5.37 (IO23), X1.4
PIN_T_RS232_RX: U5.28 (IO17), X1.8
PIN_T_RS232_TX: U5.27 (IO16), X1.6
PIN_T_RST: X1.12
RTS: Q1.1 (E), Q1.5 (B), U4.14 (!RTS)
RX: U4.2 (TXO), U5.34 (RXD0)
TX: U4.3 (RXI), U5.35 (TXD0)

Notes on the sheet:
ESP32-WROOM32
Programming
Goldpins
IR receiver
Touch button
RGB LEDS
IR transmitters
Motor

Board: 2 copper layers, 55 parts (1 on the bottom side), 48 nets, no tracks yet.

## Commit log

2024-03-25 Added hardware part
    [PCB BOTTOM.brd, PCB BOTTOM.sch, PCB TOP.brd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]
2024-03-25 Added enclosure
    [rev5 case v2.step]
2024-03-25 Update README.md - Similar devices
2024-03-25 Update README.md - First prototype
2024-03-25 Update README.md - added renders of the enclosure

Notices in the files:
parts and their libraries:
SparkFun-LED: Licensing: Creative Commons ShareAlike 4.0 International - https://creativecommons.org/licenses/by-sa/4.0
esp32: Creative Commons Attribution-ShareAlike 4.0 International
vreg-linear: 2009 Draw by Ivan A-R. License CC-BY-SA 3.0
